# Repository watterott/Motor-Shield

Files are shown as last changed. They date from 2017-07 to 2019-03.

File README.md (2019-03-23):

# Motor-Shield
Shield for Arduino to drive DC-Motors, Solenoids or Relays.

* Compatible with [Arduino Motor-Shield](https://www.arduino.cc/en/Main/ArduinoMotorShieldR3)
* ST L298 Dual Full-Bridge Driver (2A per channel or 4A max)
* Open-Source and released under the [Creative Commons Attribution Share-Alike License](https://creativecommons.org/licenses/by-sa/4.0/).
* **[Documentation on learn.watterott.com](https://learn.watterott.com)**

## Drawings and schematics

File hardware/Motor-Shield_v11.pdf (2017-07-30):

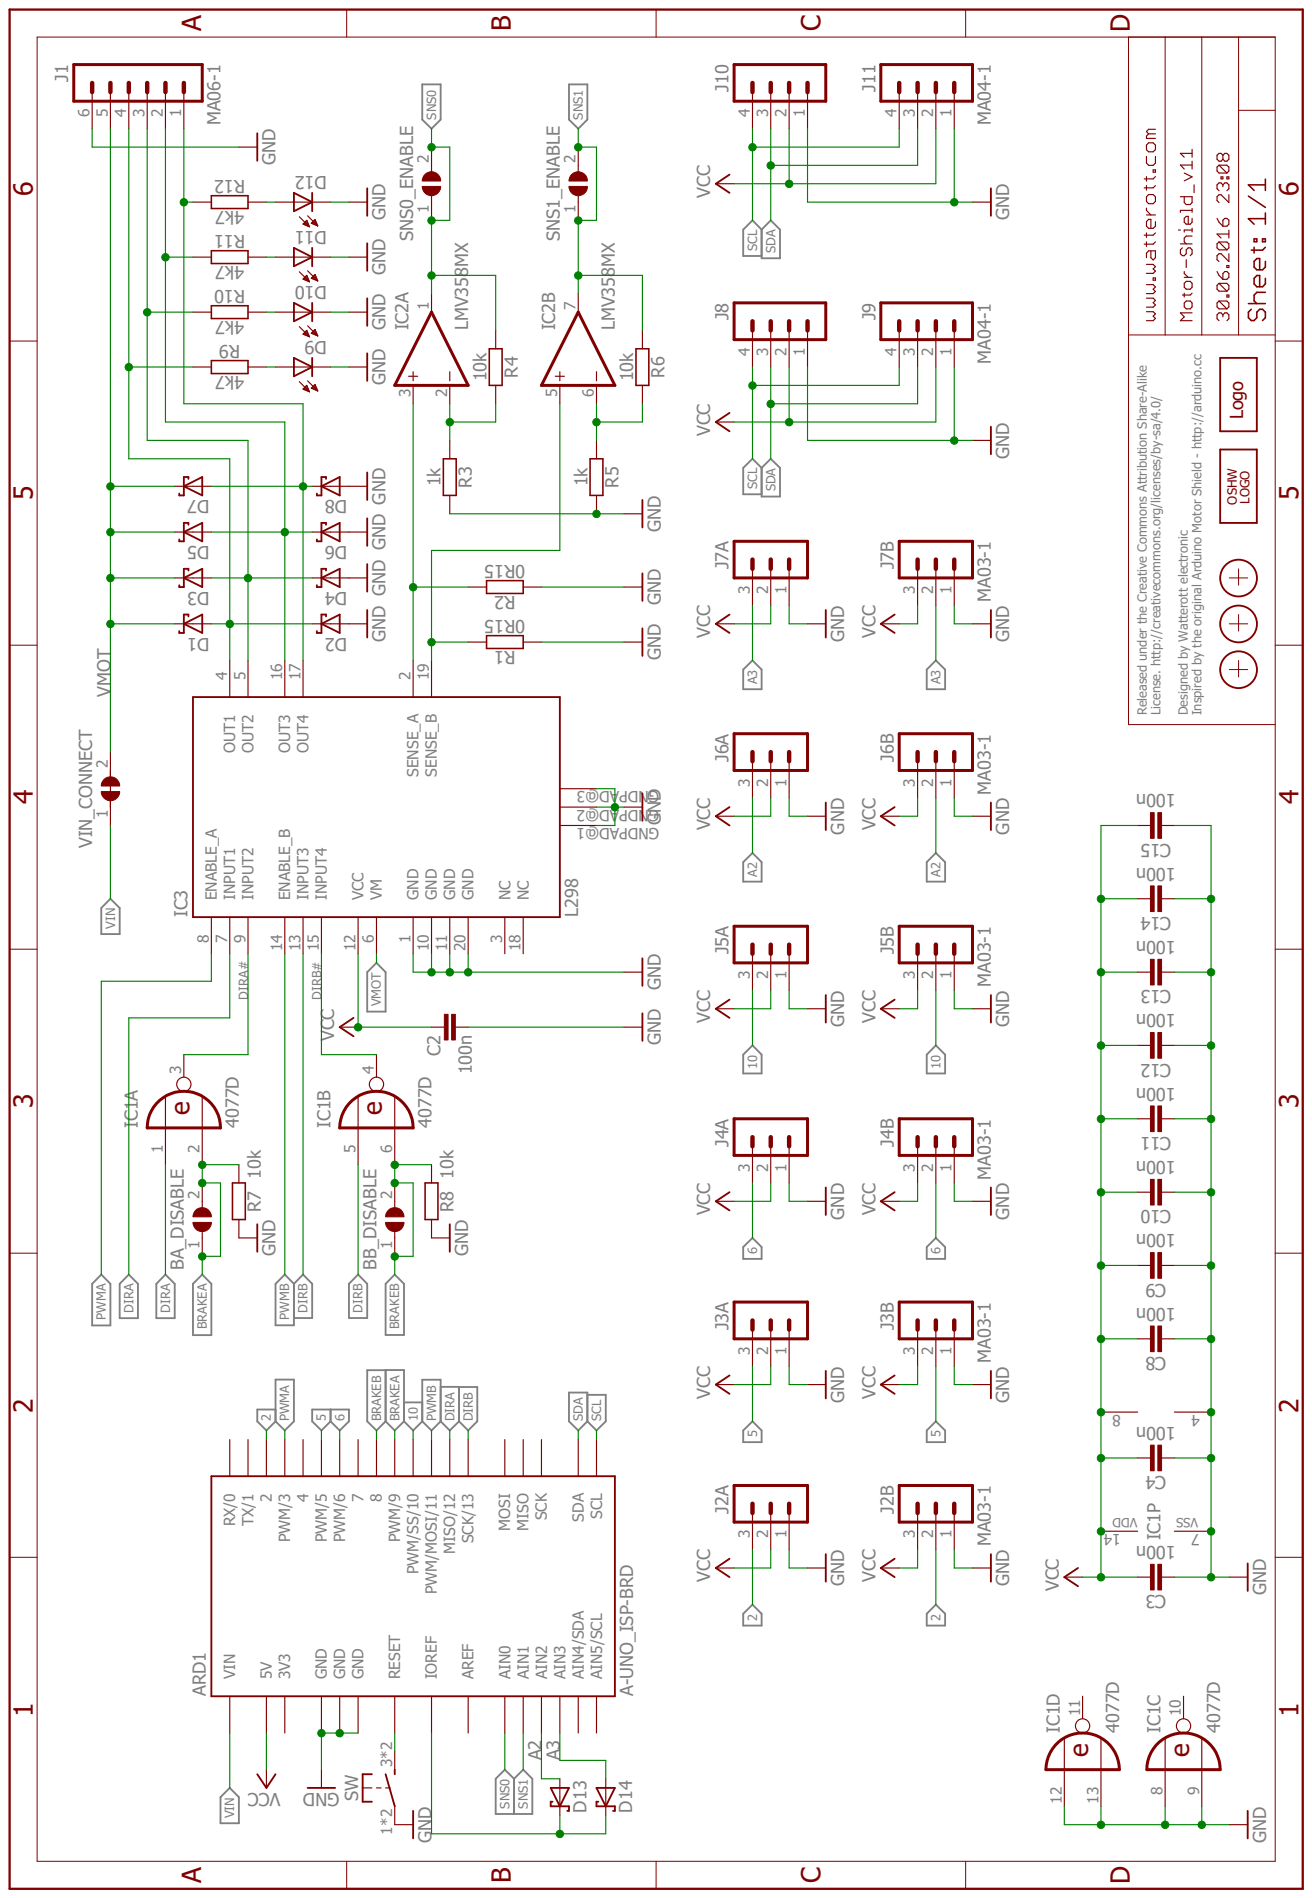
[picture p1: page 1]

GND GND

Inspired by the original Arduino Motor Shield - http://arduino.cc

Released under the Creative Commons Attribution Share-Alike

License. http://creativecommons.org/licenses/by-sa/4.0/ Designed by Watterott electronic

VCC VCC

VCC VCC VCC

GND GND GND

8 PWM/9 PWM/SS/10 PWM/MOSI/11 MISO/12 SCK/13 AIN1 AIN2 AIN3 AIN4/SDA

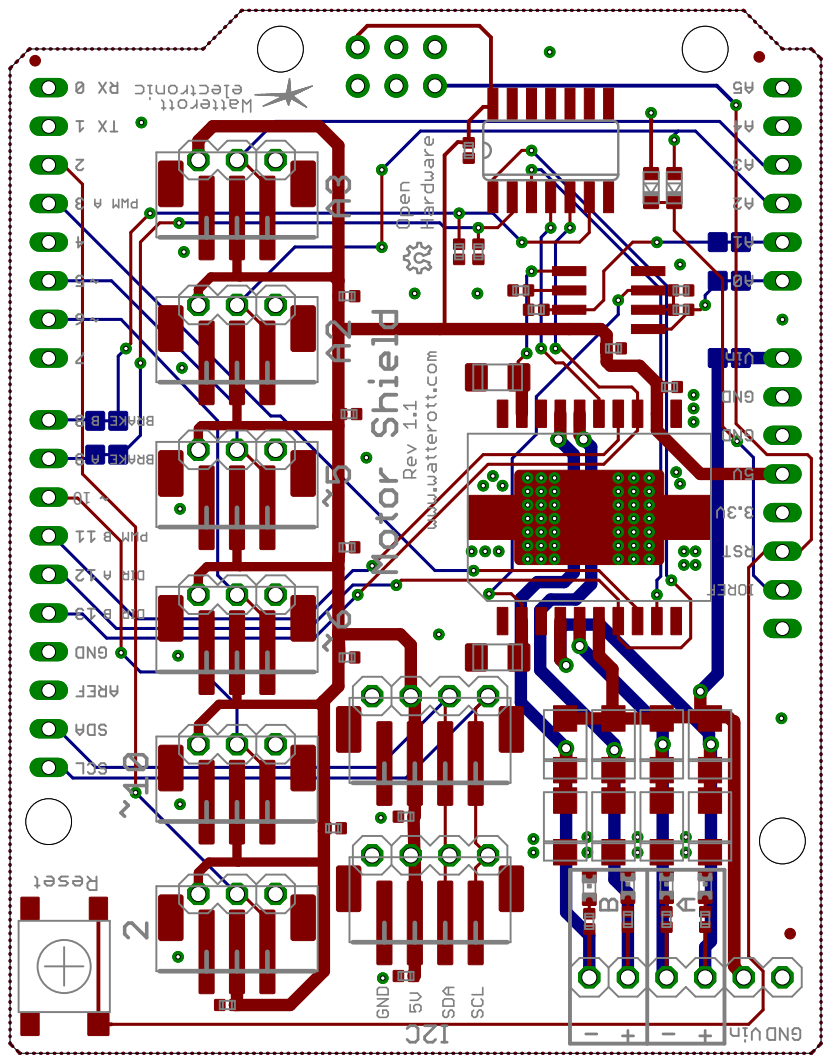
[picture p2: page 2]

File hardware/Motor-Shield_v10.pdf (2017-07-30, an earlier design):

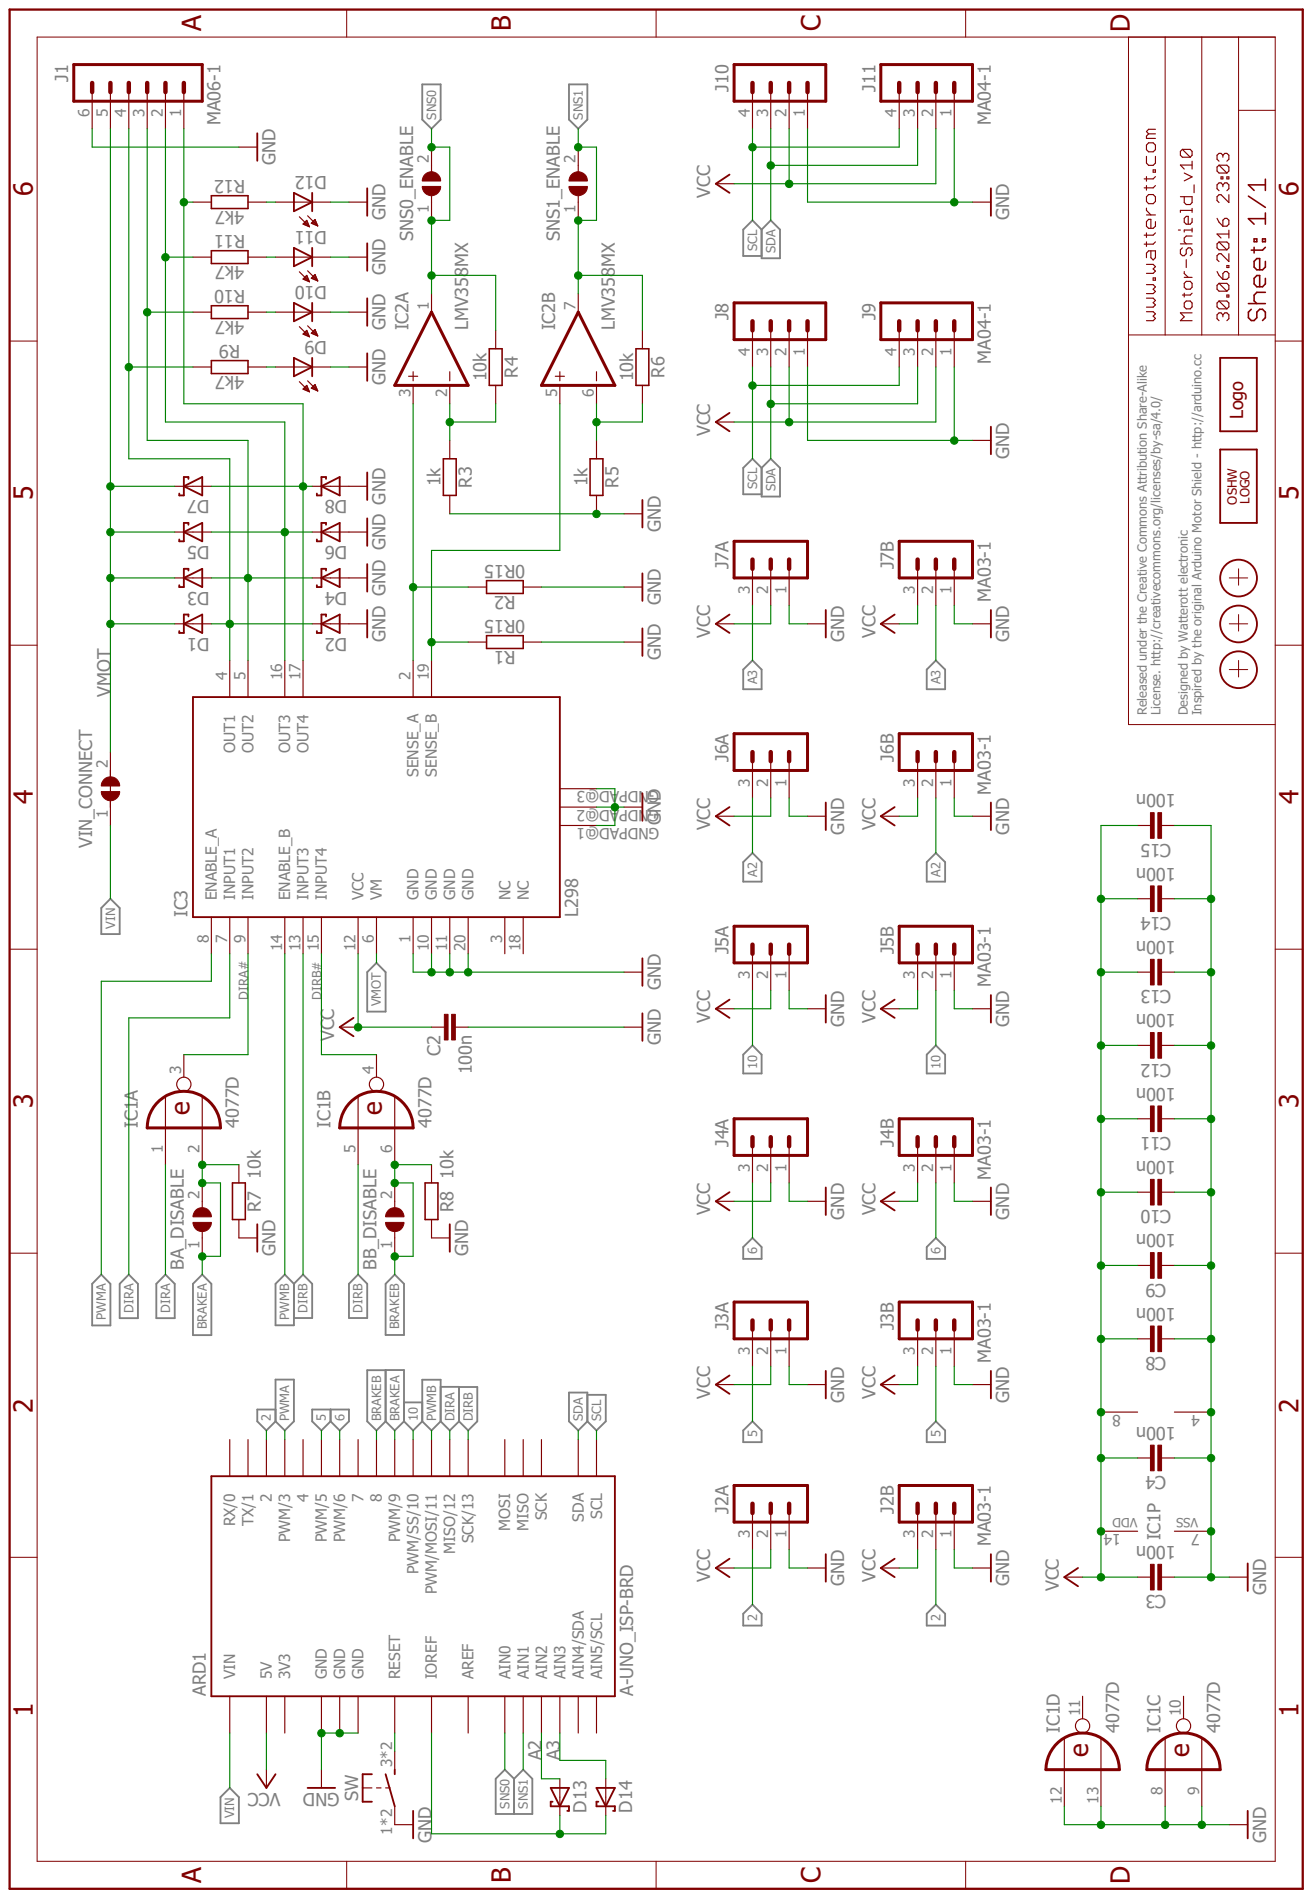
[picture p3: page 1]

GND GND

Inspired by the original Arduino Motor Shield - http://arduino.cc

Released under the Creative Commons Attribution Share-Alike

License. http://creativecommons.org/licenses/by-sa/4.0/ Designed by Watterott electronic

VCC VCC

VCC VCC VCC

GND GND GND

8 PWM/9 PWM/SS/10 PWM/MOSI/11 MISO/12 SCK/13 AIN1 AIN2 AIN3 AIN4/SDA

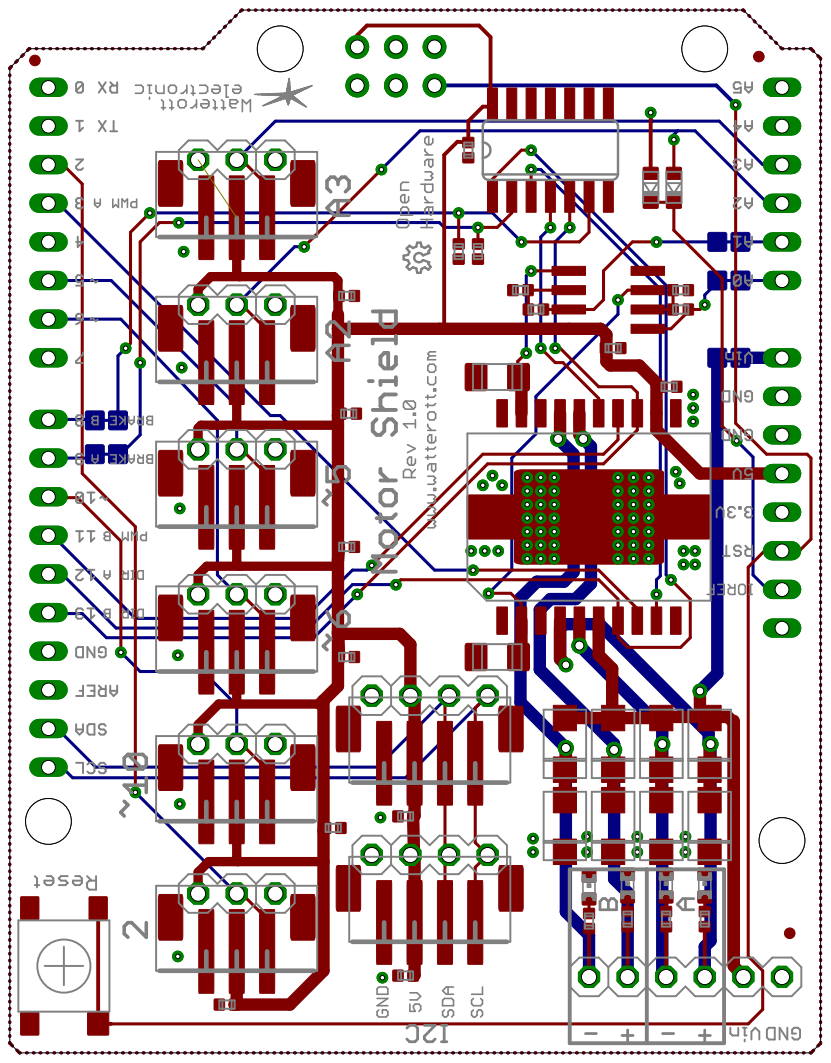
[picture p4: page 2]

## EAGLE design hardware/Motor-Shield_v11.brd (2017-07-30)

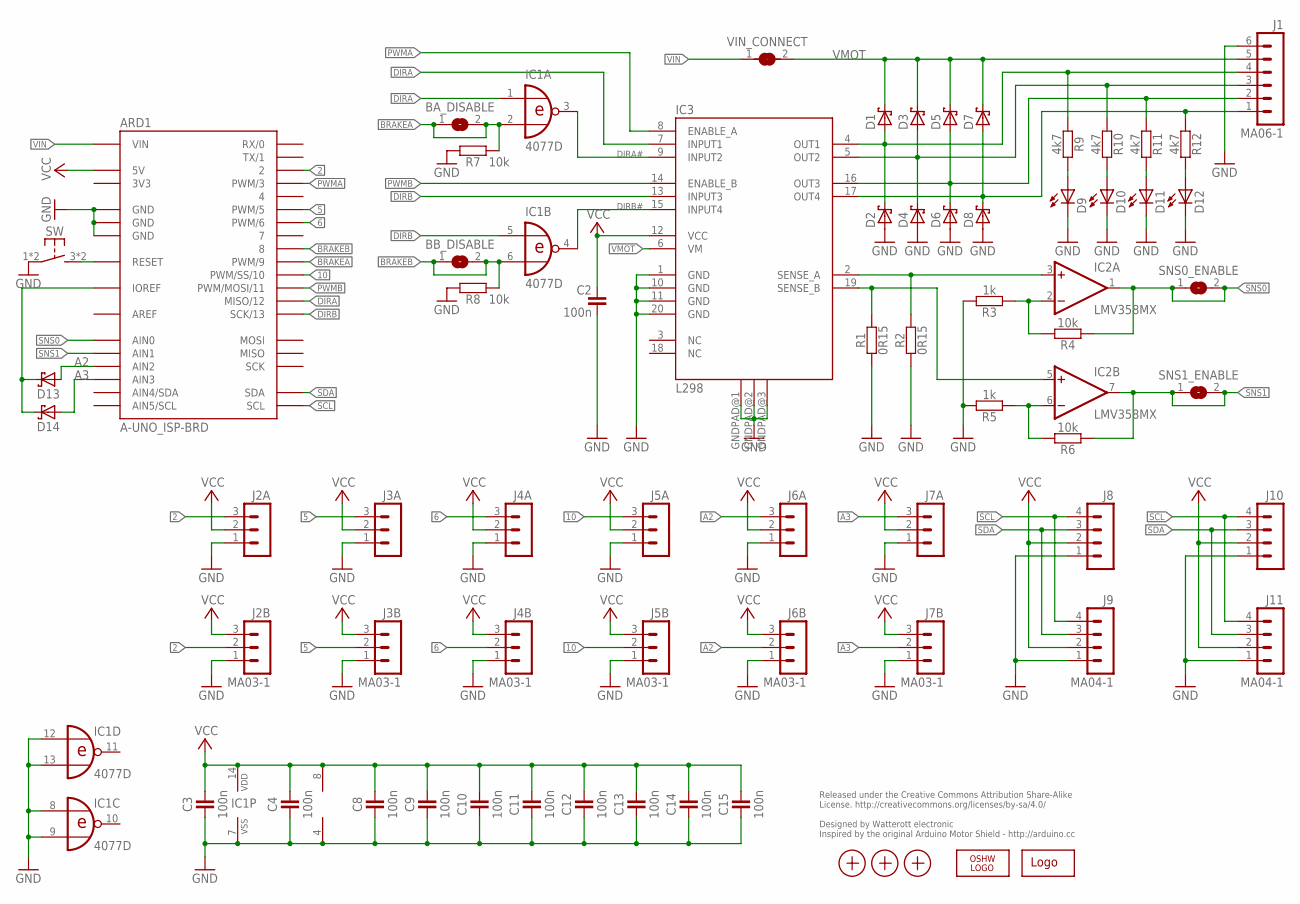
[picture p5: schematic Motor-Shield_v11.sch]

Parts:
ARD1: A-UNO_ISP-BRD; A-UNO-ISP
BA_DISABLE: JUMPER2-0603
BB_DISABLE: JUMPER2-0603
C2, C3, C4, C8, C9, C10, C11, C12, C13, C14, C15: 100n; C0402
D1, D2, D3, D4, D5, D6, D7, D8: D_SS14; DO214AC
D9, D10, D11, D12: LED-0603; C0603
D13, D14: D_SCHOTTKY-SOD110; SOD110
IC1: 4077D; SO14
IC2: LMV358MX; SO08
IC3: L298; POWERSO20
J1: MA06-1
J2A, J3A, J4A, J5A, J6A, J7A: JST_PH_3B3B-PH-SM4-TB; JST_B3B-PH-SM4-TB
J2B, J3B, J4B, J5B, J6B, J7B: MA03-1
J8, J10: JST_PH_4B4B-PH-SM4-TB; JST_B4B-PH-SM4-TB
J9, J11: MA04-1
LOGO1: LOGO-S_PLACE_S; SPARK_TPLACE_S
LOGO2: OSHW_LOGOX0070; OSHW_6X70
R1, R2: 0R15; C1206
R3, R5: 1k; C0402
R4, R6, R7, R8: 10k; C0402
R9, R10, R11, R12: 4k7; C0402
SNS0_ENABLE, SNS1_ENABLE: JUMPER2-0603
SW: SW-TACTILE-6X6_SMD; SW6X6_SMD
VIN_CONNECT: JUMPER2-0603
X1, X2, X3: PASSER-07; PASSER_07MM

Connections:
2: ARD1.2, J2A.3, J2B.2
3V3: ARD1.3V3
5: ARD1.5 (PWM/5), J3A.3, J3B.2
6: ARD1.6 (PWM/6), J4A.3, J4B.2
10: ARD1.10 (PWM/SS/10), J5A.3, J5B.2
A2: ARD1.A2 (AIN2), D13.A, J6A.3, J6B.2
A3: ARD1.A3 (AIN3), D14.A, J7A.3, J7B.2
AREF: ARD1.AREF
BRAKEA: ARD1.9 (PWM/9), BA_DISABLE.1, BA_DISABLE.2, IC1.2 (I1), R7.1
BRAKEB: ARD1.8, BB_DISABLE.1, BB_DISABLE.2, IC1.6 (I1), R8.1
DIRA: ARD1.12 (MISO/12), IC1.1 (I0), IC3.7 (INPUT1)
DIRA#: IC1.3 (O), IC3.9 (INPUT2)
DIRB: ARD1.13 (SCK/13), IC1.5 (I0), IC3.13 (INPUT3)
DIRB#: IC1.4 (O), IC3.15 (INPUT4)
GND: ARD1.GND@1 (GND), ARD1.GND@2 (GND), ARD1.GND@3 (GND), ARD1.GND@4 (GND), C2.1, C3.1, C4.1, C8.1, C9.1, C10.1, C11.1, C12.1, C13.1, C14.1, C15.1, D2.1 (A), D4.1 (A), D6.1 (A), D8.1 (A), D9.C, D10.C, D11.C, D12.C, IC1.7 (VSS), IC1.8 (I0), IC1.9 (I1), IC1.12 (I0), IC1.13 (I1), IC2.4 (V-), IC3.1 (GND), IC3.10 (GND), IC3.11 (GND), IC3.20 (GND), IC3.GNDPAD@1 (GNDPAD), IC3.GNDPAD@2 (GNDPAD), IC3.GNDPAD@3 (GNDPAD), J1.6, J2A.1, J2B.1, J3A.1, J3B.1, J4A.1, J4B.1, J5A.1, J5B.1, J6A.1, J6B.1, J7A.1, J7B.1, J8.1, J9.1, J10.1, J11.1, R1.1, R2.1, R3.2, R5.2, R7.2, R8.2, SW.1, SW.2 (P1)
IOREF: ARD1.IOREF, D13.C, D14.C
unnamed: D9.A, R9.2
unnamed: D10.A, R10.2
unnamed: IC2.2 (-IN), R3.1, R4.2
unnamed: IC2.6 (-IN), R5.1, R6.2
unnamed: D11.A, R11.2
unnamed: D12.A, R12.2
unnamed: ARD1.RST@1 (RESET), ARD1.RST@2 (RESET), SW.3 (S1), SW.4 (S1)
OUT1: D1.1 (A), D2.2 (C), IC3.4 (OUT1), J1.4, R9.1
OUT2: D3.1 (A), D4.2 (C), IC3.5 (OUT2), J1.3, R10.1
OUT3: D5.1 (A), D6.2 (C), IC3.16 (OUT3), J1.2, R11.1
OUT4: D7.1 (A), D8.2 (C), IC3.17 (OUT4), J1.1, R12.1
PWMA: ARD1.3 (PWM/3), IC3.8 (ENABLE_A)
PWMB: ARD1.11 (PWM/MOSI/11), IC3.14 (ENABLE_B)
SCL: ARD1.SCL, J8.4, J9.4, J10.4, J11.4
SDA: ARD1.SDA, J8.3, J9.3, J10.3, J11.3
SENSE_A: IC2.3 (+IN), IC3.2 (SENSE_A), R2.2
SENSE_B: IC2.5 (+IN), IC3.19 (SENSE_B), R1.2
SNS0: ARD1.A0 (AIN0), IC2.1 (OUT), R4.1, SNS0_ENABLE.1, SNS0_ENABLE.2
SNS1: ARD1.A1 (AIN1), IC2.7 (OUT), R6.1, SNS1_ENABLE.1, SNS1_ENABLE.2
VCC: ARD1.5V, ARD1.VCC (5V), C2.2, C3.2, C4.2, C8.2, C9.2, C10.2, C11.2, C12.2, C13.2, C14.2, C15.2, IC1.14 (VDD), IC2.8 (V+), IC3.12 (VCC), J2A.2, J2B.3, J3A.2, J3B.3, J4A.2, J4B.3, J5A.2, J5B.3, J6A.2, J6B.3, J7A.2, J7B.3, J8.2, J9.2, J10.2, J11.2
VIN: ARD1.VIN, VIN_CONNECT.1
VMOT: D1.2 (C), D3.2 (C), D5.2 (C), D7.2 (C), IC3.6 (VM), J1.5, VIN_CONNECT.2

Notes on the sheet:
Released under the Creative Commons Attribution Share-Alike License. http://creativecommons.org/licenses/by-sa/4.0/ Designed by Watterott electronic Inspired by the original Arduino Motor Shield - http://arduino.cc

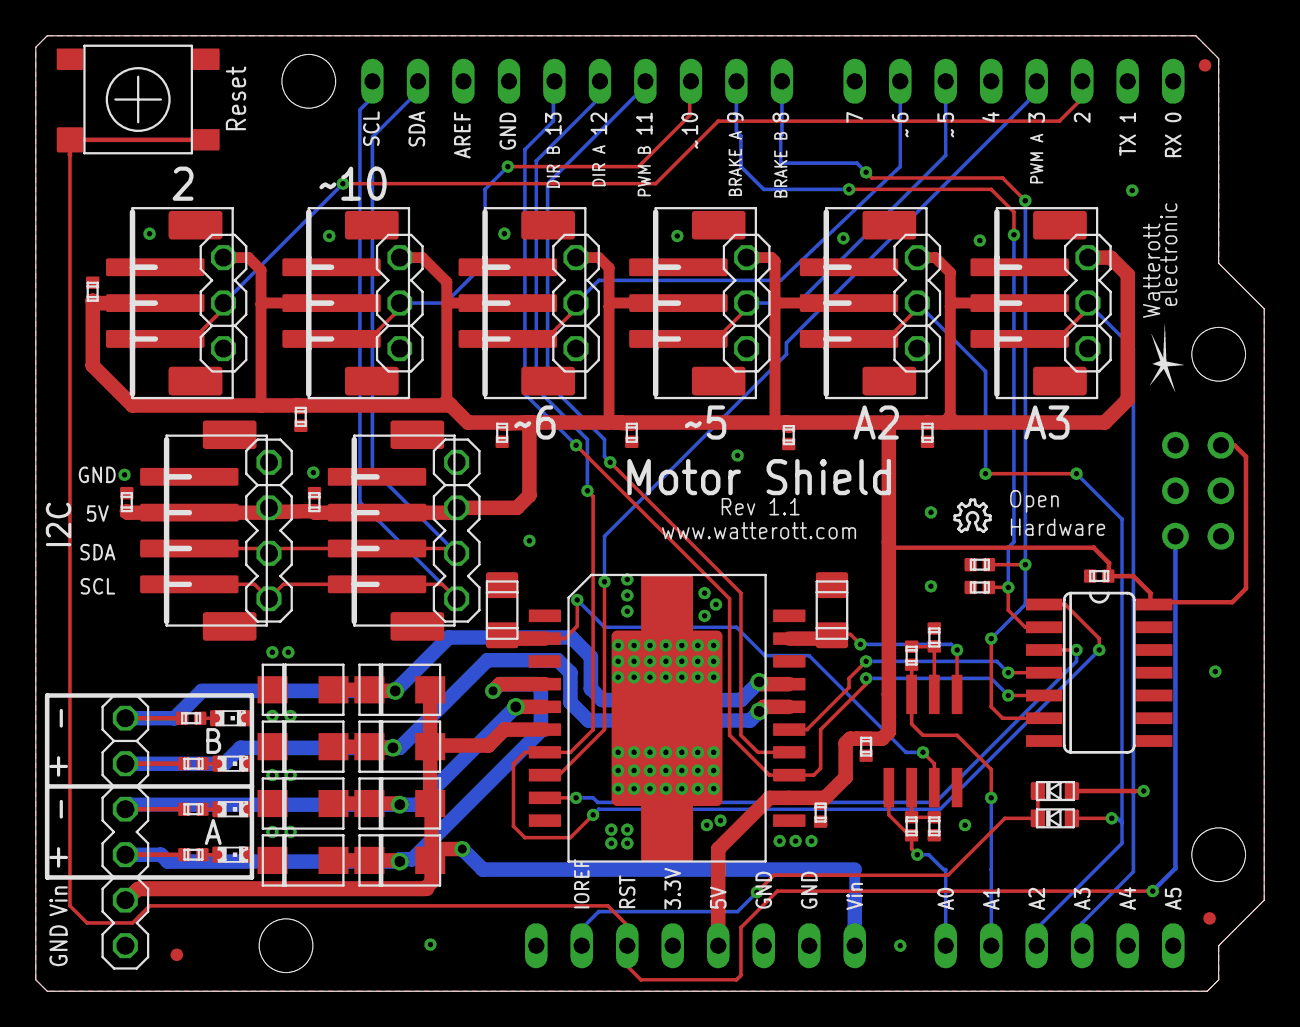
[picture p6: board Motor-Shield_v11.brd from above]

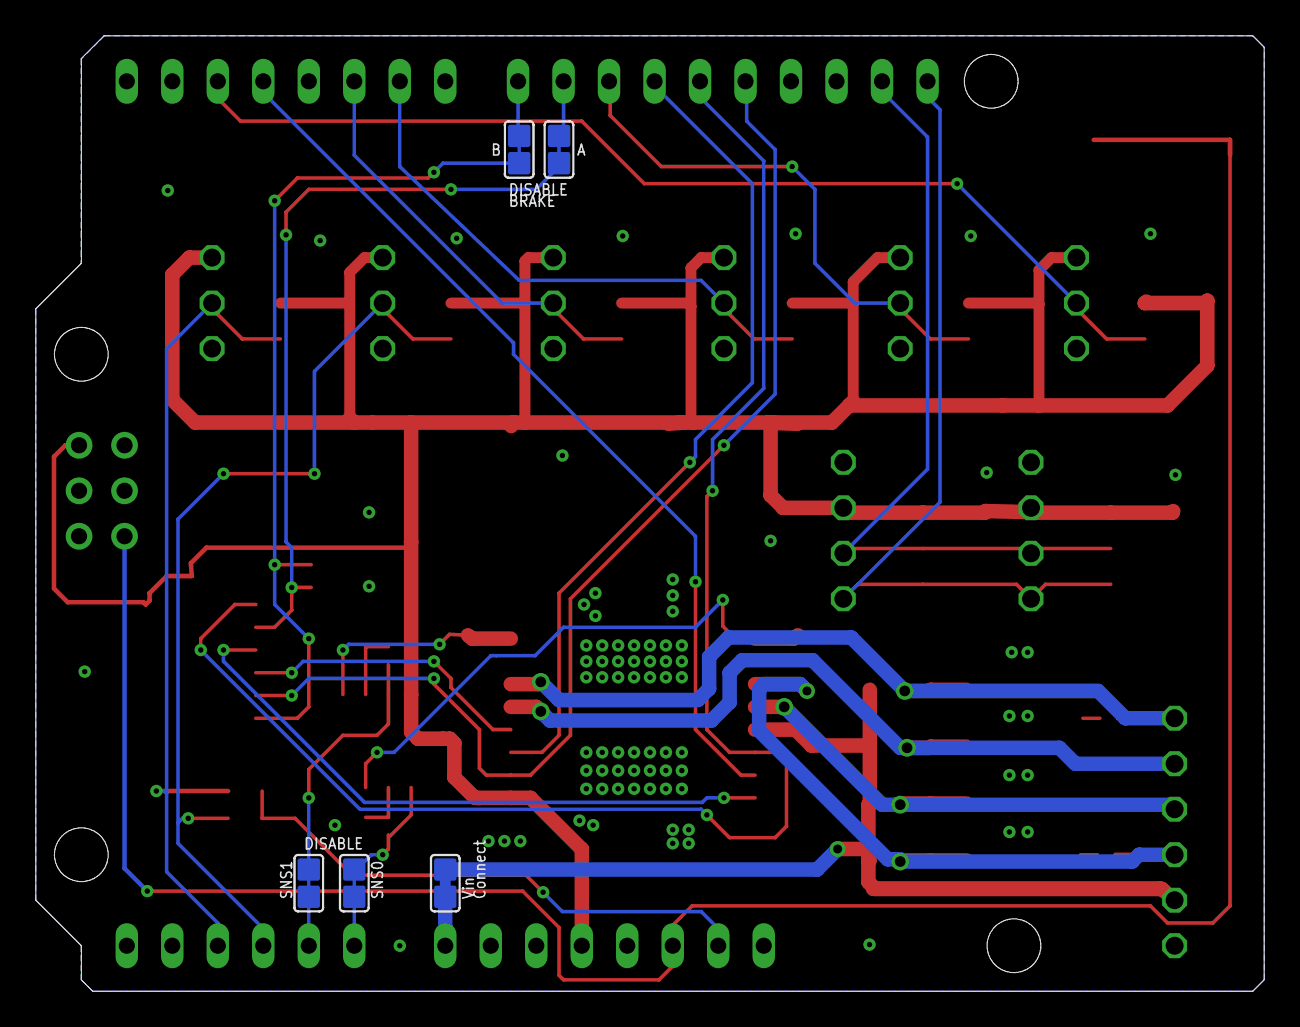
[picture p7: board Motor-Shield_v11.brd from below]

Board: 2 copper layers, 68.6 x 53.3 mm, 69 parts (5 on the bottom side), 36 nets.
